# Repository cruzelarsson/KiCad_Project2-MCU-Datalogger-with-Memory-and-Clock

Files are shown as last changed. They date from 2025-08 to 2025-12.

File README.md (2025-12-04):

MCU Datalogger with memory and clock 

• Designed and debugged multi-layer PCB design using microcontroller, EEPROM, and RTC module with a regulated power supply, improving thermal performance ~30% by utilizing accurate design & routing methodologies ensuring zero DRC & ERC errors.

• Evaluated electrical and firmware-level interactions between MCU and peripherals for stable operation.

• Validated MCU communication protocols using I2C for peripheral data exchange.

•	Produced a compact design with status LEDs, mounting holes and modular connectors, ensuring physical durability and visible feedback. 

-------------------------------------------------------------------------------------------------------------------------------------------------------
This project — MCU Datalogger with Memory and Clock — was supported by PCBWay through their PCB prototyping sponsorship program.

PCBWay provided high-quality manufactured boards that arrived perfectly aligned and finished. The fabrication quality was excellent, with sharp silkscreen printing, clean solder masks, and precise drill accuracy.

A huge thanks to PCBWay for their support in helping bring this project to life. Their fast turnaround and reliable service made the prototyping process straightforward and efficient.

Below you will find the printed out board; the missing components will be added and uploaded soon. Thank you!





-------------------------------------------------------------------------------------------------------------------------------------------------------
3D layout of 2 layer PCB (final design)





-------------------------------------------------------------------------------------------------------------------------------------------------------

PCB Board layout with board specifications 





-------------------------------------------------------------------------------------------------------------------------------------------------------

Schematic Editor Layout of MCU Datalogger



-------------------------------------------------------------------------------------------------------------------------------------------------------

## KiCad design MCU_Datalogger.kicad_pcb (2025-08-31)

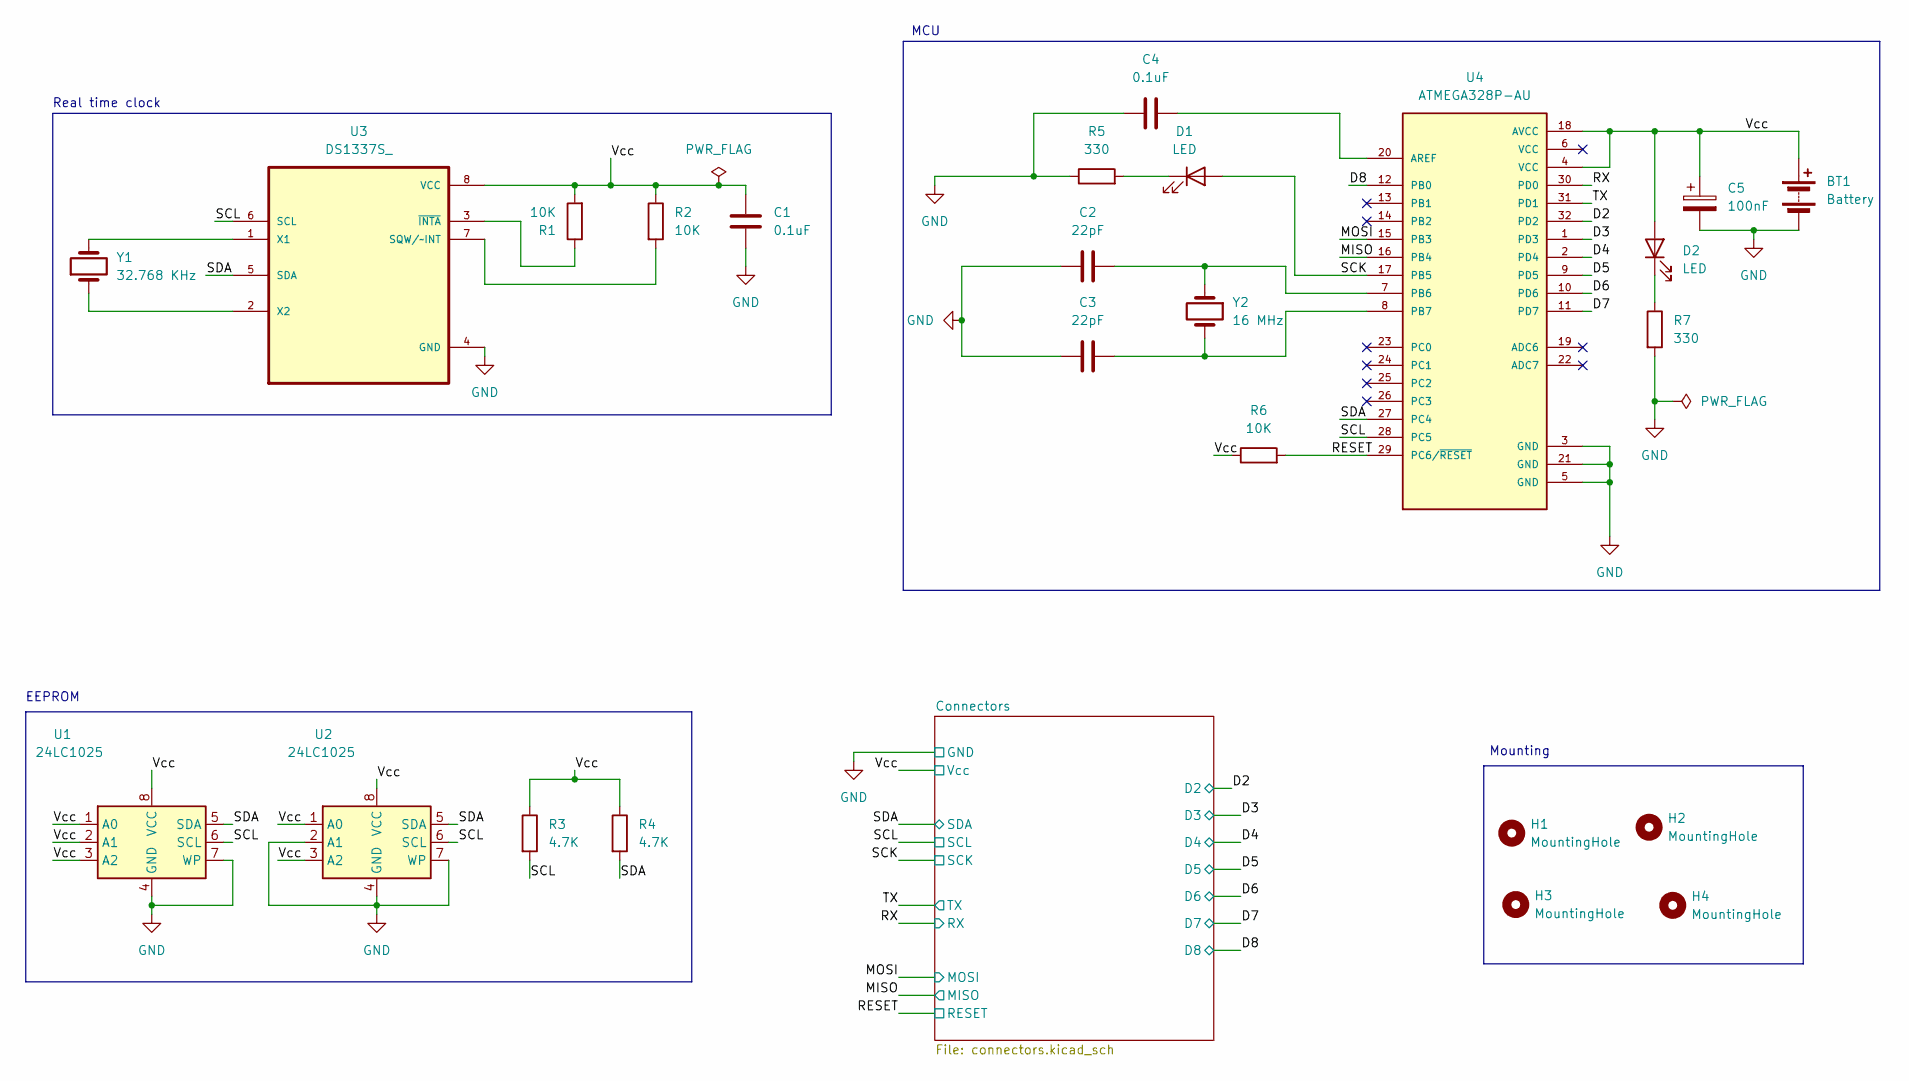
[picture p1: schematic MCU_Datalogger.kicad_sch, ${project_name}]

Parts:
BT1: Battery; PinHeader_1x02_P2.54mm_Vertical
C1, C4: 0.1uF; C_0805_2012Metric
C2, C3: 22pF; C_0805_2012Metric
C5: 100nF; C_0805_2012Metric
D1, D2: LED; LED_0805_2012Metric
H1, H2, H3, H4: MountingHole; MountingHole_2.1mm
R1, R2, R6: 10K; R_0805_2012Metric
R3, R4: 4.7K; R_0805_2012Metric
R5, R7: 330; R_0805_2012Metric
U1, U2: 24LC1025; SOIC-8_5.3x5.3mm_P1.27mm
U3: DS1337S_; SOIC127P600X175-8N
U4: ATMEGA328P-AU; QFP80P900X900X120-32N; PARTREV 8271A
Y1: 32.768 KHz; Crystal_SMD_5032-2Pin_5.0x3.2mm_HandSoldering
Y2: 16 MHz; Crystal_SMD_5032-2Pin_5.0x3.2mm_HandSoldering

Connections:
/D2: U4.32 (PD2); also elsewhere on the board
/D3: U4.1 (PD3); also elsewhere on the board
/D4: U4.2 (PD4); also elsewhere on the board
/D5: U4.9 (PD5); also elsewhere on the board
/D6: U4.10 (PD6); also elsewhere on the board
/D7: U4.11 (PD7); also elsewhere on the board
/D8: U4.12 (PB0); also elsewhere on the board
/MISO: U4.16 (PB4); also elsewhere on the board
/MOSI: U4.15 (PB3); also elsewhere on the board
/RESET: R6.2, U4.29 (PC6/~RESET); also elsewhere on the board
/RX: U4.30 (PD0); also elsewhere on the board
/SCK: D1.2 (A), U4.17 (PB5); also elsewhere on the board
/SCL: R3.2, U1.6 (SCL), U2.6 (SCL), U3.6 (SCL), U4.28 (PC5); also elsewhere on the board
/SDA: R4.2, U1.5 (SDA), U2.5 (SDA), U3.5 (SDA), U4.27 (PC4); also elsewhere on the board
/TX: U4.31 (PD1); also elsewhere on the board
/Vcc: BT1.1 (+), C1.1, C5.1, D2.2 (A), R1.2, R2.1, R3.1, R4.1, R6.1, U1.1 (A0), U1.2 (A1), U1.3 (A2), U1.8 (VCC), U2.1 (A0), U2.3 (A2), U2.8 (VCC), U3.8 (VCC), U4.4 (VCC), U4.18 (AVCC); also elsewhere on the board
GND: BT1.2 (-), C1.2, C2.1, C3.1, C4.1, C5.2, R5.1, R7.2, U1.4 (GND), U1.7 (WP), U2.2 (A1), U2.4 (GND), U2.7 (WP), U3.4 (GND), U4.3 (GND), U4.5 (GND), U4.21 (GND); also elsewhere on the board
unnamed: D1.1 (K), R5.2
unnamed: D2.1 (K), R7.1
unnamed: R2.2, U3.7 (SQW/~INT)
unnamed: U3.1 (X1), Y1.2
unnamed: U3.2 (X2), Y1.1
unnamed: R1.1, U3.3 (~INTA)
unnamed: C4.2, U4.20 (AREF)
unnamed: C2.2, U4.7 (PB6), Y2.1
unnamed: C3.2, U4.8 (PB7), Y2.2

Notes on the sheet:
Mounting
Real time clock
MCU
EEPROM

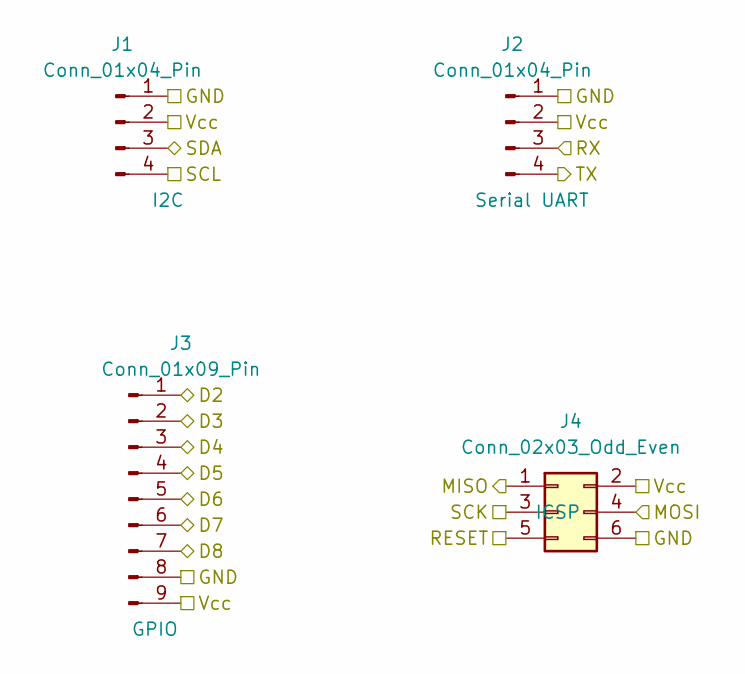
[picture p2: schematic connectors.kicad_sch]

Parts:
J1, J2: Conn_01x04_Pin; PinHeader_1x04_P2.54mm_Vertical
J3: Conn_01x09_Pin; PinHeader_1x09_P2.54mm_Vertical
J4: Conn_02x03_Odd_Even; PinHeader_2x03_P2.54mm_Vertical

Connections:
/D2: J3.1; also elsewhere on the board
/D3: J3.2; also elsewhere on the board
/D4: J3.3; also elsewhere on the board
/D5: J3.4; also elsewhere on the board
/D6: J3.5; also elsewhere on the board
/D7: J3.6; also elsewhere on the board
/D8: J3.7; also elsewhere on the board
/MISO: J4.1; also elsewhere on the board
/MOSI: J4.4; also elsewhere on the board
/RESET: J4.5; also elsewhere on the board
/RX: J2.3; also elsewhere on the board
/SCK: J4.3; also elsewhere on the board
/SCL: J1.4; also elsewhere on the board
/SDA: J1.3; also elsewhere on the board
/TX: J2.4; also elsewhere on the board
/Vcc: J1.2, J2.2, J3.9, J4.2; also elsewhere on the board
GND: J1.1, J2.1, J3.8, J4.6; also elsewhere on the board

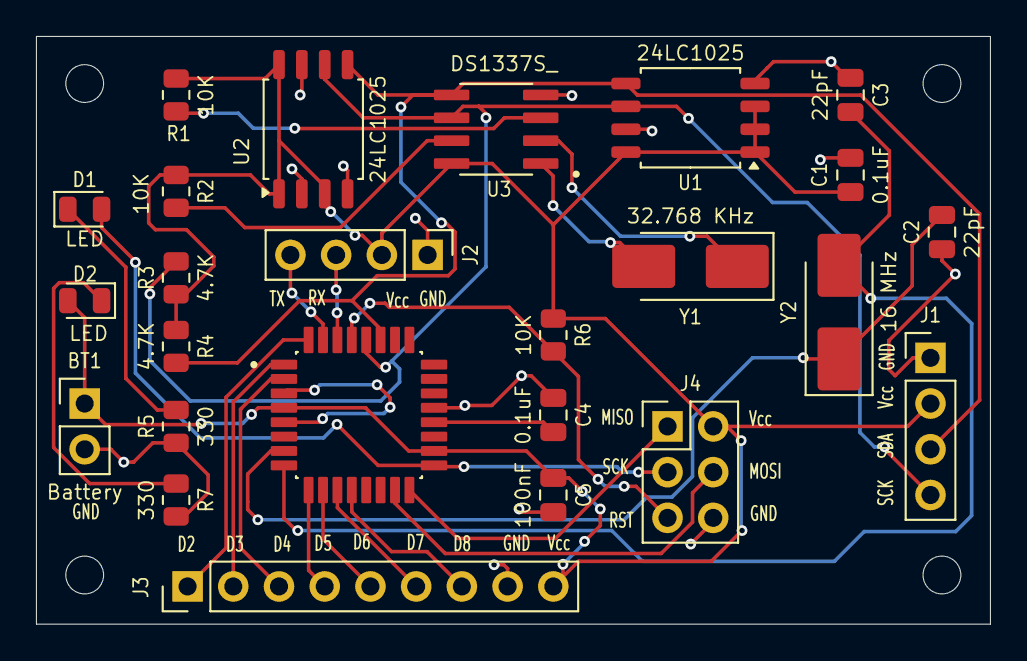
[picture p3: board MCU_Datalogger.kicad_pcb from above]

Board: 2 copper layers, 53.0 x 32.6 mm, 29 parts (0 on the bottom side), 26 nets.

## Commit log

2025-08-30 First commit of New Project
    [MCU_Datalogger.kicad_pcb, MCU_Datalogger.kicad_sch]
2025-08-30 Added the required symbols for the Project to the added schematics sheets
    [connectors.kicad_sch]
2025-08-30 Saving changes
    [MCU_Datalogger.kicad_sch]
2025-08-30 Change in component placements
    [MCU_Datalogger.kicad_sch, connectors.kicad_sch]
2025-08-30 Assigned footprints to components
    [MCU_Datalogger.kicad_sch, connectors.kicad_sch]
2025-08-30 Added wiring to main sheet
    [MCU_Datalogger.kicad_sch, connectors.kicad_sch]
2025-08-30 Completed wiring of second sheet + added connectection between the 2 sheets
    [MCU_Datalogger.kicad_sch, connectors.kicad_sch]
2025-08-30 Added comments and made the schematics neat
    [MCU_Datalogger.kicad_sch, connectors.kicad_sch]
2025-08-30 Completed placements of footprints
    [MCU_Datalogger.kicad_pcb]
2025-08-31 Added proper Routing plus GND
2025-08-31 Fixed various errors and made the PCB more redeable
    [MCU_Datalogger.kicad_pcb, MCU_Datalogger.kicad_sch, connectors.kicad_sch]
2025-08-31 Added silkscreens and labels
    [MCU_Datalogger.kicad_pcb]
2025-08-31 Fixed 2 bugs in the Schematics diagram
    [MCU_Datalogger.kicad_sch, connectors.kicad_sch]
2025-08-31 Additional bug fixes with rerouting of Routes
    [MCU_Datalogger.kicad_pcb]
2025-08-31 Check point of Project Completion
    [MCU_Datalogger-B_Cu.gbl, MCU_Datalogger-B_Mask.gbs, MCU_Datalogger-B_Paste.gbp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]
2025-08-31 Added missing 3D models [Visual Fix]
    [MCU_Datalogger.kicad_pcb]
2025-08-31 Completion of MCU Data logger 2 layer project
    [MCU_Datalogger.kicad_pcb]
